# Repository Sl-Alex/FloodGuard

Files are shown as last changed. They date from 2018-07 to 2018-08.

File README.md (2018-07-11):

# General description
Autonomous flood protection system, which can work for months from a single 18650 Li-ion battery.
Includes a battery charger as well as a HW monitoring circuit. Includes power MOSFET for external valve control circuit. Even if SW is stuck or microcontroller is dead you will hear beeping informing you that something is wrong.
Two protected guard inputs make a redundant and reliable system.

# Hardware
Both schematic and PCB were created with KiCAD. KiCAD project is located in the PCB subfolder. Project uses components from my [KiCAD_libs](https://github.com/Sl-Alex/KiCAD_libs) repository.<br />

# Software
Project is created in [EmBitz](https://www.embitz.org/). Project skeleton is created in STM32CubeMX.<br />

# Licensing
The whole project is available under GPL v3 license (see [LICENSE](LICENSE) file), except of files, which clearly mention other license type in the file header.

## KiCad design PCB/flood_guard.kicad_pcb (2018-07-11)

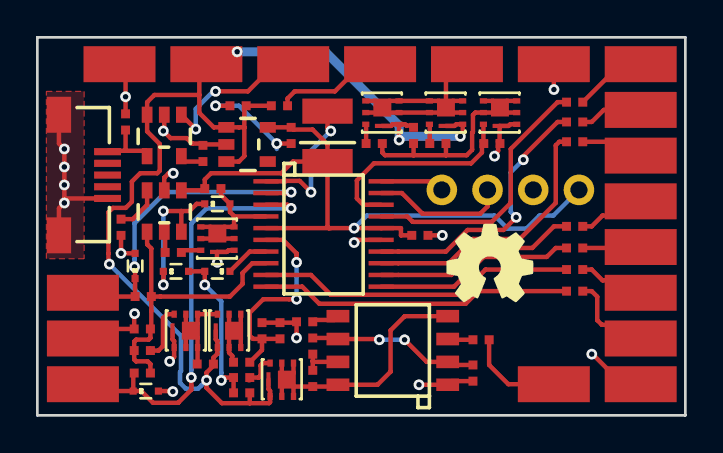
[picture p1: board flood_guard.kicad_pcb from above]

Board: 2 copper layers, 36.0 x 21.0 mm, 77 parts (0 on the bottom side), 49 nets.

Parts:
C1, C2, C3, C4, C5, C7, C8: capacitor; 0402_C
C6: capacitor_el; case_B
D1, D2, D3: diode; SOD523
D4, D5: zener; SOD523
LG?1: LOGO; OSHW
R1, R2, R3, R4, R5, R6, R7, R8, R9, R10, R11, R12, R13, R14, R15, R16, R17, R18, R19, R20, R21, R22, R23, R24, R25, R26, R27, R28: resistor; 0402_R
U1: TPL5010; SOT23-6
U2: NCP551; SOT23-5
U3: TS555CN; SO8
U4: STC4054; SOT23-5
U5: STM32F030F4P6; TSSOP20
VT1, VT2, VT3: MOSFET_N_DGS; PQFN2x2
VT4, VT6, VT7, VT8: MOSFET_P_DGS; PQFN2x2
X1: USB2_MICRO_B_F1
X2: BUZZER+; PLS1_SMD
X4: BAT+; PLS1_SMD
X5: BAT-; PLS1_SMD
X6: CHG_LED-; PLS1_SMD
X7: CHG_LED+; PLS1_SMD
X8: 3V3; PLS1
X9: GND; PLS1
X10: SWCLK; PLS1
X11: SWDIO; PLS1
X12: VOUT; PLS1_SMD
X13, X16, X25: GND; PLS1_SMD
X14: GUARD0; PLS1_SMD
X15: GUARD1; PLS1_SMD
X18: LED0; PLS1_SMD
X19: LED1; PLS1_SMD
X20: LED2; PLS1_SMD
X21: LED3; PLS1_SMD
X22: LED4; PLS1_SMD
X23: LED5; PLS1_SMD
X24: LED6; PLS1_SMD

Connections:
3V3: C5.2, C6.1, C7.2, R8.2, U1.1, U2.5, U5.5, U5.16, X8.1
/BUZZER_PWR: R2.2, U3.4, U3.8, VT4.1
/BUZ_EN: D2.2, U5.7
/GUARD0: D4.2, R17.2, U5.2, X14.1
/GUARD1: D5.2, R18.2, U5.3, X15.1
/LED0: R21.1, U5.10
/LED1: R22.1, U5.9
/LED2: R23.1, U5.11
/LED3: R24.1, U5.12
/LED4: R25.1, U5.13
/LED5: R26.1, U5.14
/LED6: R27.1, U5.17
/LOAD: R13.2, U5.18, VT3.2
/MEAS: R11.1, R12.1, R17.1, R18.1, U1.4, U5.8
/SWCLK: U5.20, X10.1
/SWDIO: U5.19, X11.1
/VADC: C8.1, R19.1, R20.2, U5.6
/VBAT: C4.2, R7.1, R9.2, R14.2, R28.1, U2.1, U2.3, U4.3, VT4.3, VT6.3, VT7.3, VT8.3, X4.1
/VOUT: VT6.1, VT8.1, X12.1
/WAKE: R6.1, U1.5
/~CPU_RST: D1.1, R8.1, U5.4, VT1.1
/~RST: D1.2, D3.2, U1.6
GND: C1.1, C2.1, C3.1, C4.1, C5.1, C6.2, C7.1, C8.2, D4.1, D5.1, R1.1, R4.1, R11.2, R13.1, R19.2, U1.2, U2.2, U3.1, U4.2, U5.1, U5.15, VT1.3, VT2.3, VT3.3, X1.5, X1.6, X1.7, X5.1, X9.1, X13.1, X16.1, X25.1
unnamed: C1.2, R3.1, U3.2, U3.6
unnamed: C2.2, U3.5
unnamed: C3.2, U4.4, X1.1
unnamed: D2.1, D3.1, R9.1, R10.1
unnamed: R1.2, U1.3
unnamed: R2.1, R3.2, U3.7
unnamed: R4.2, U4.5
unnamed: R5.1, U3.3
unnamed: R5.2, X2.1
unnamed: R6.2, VT1.2
unnamed: R7.2, X7.1
unnamed: R10.2, VT4.2
unnamed: R12.2, VT2.2
unnamed: R14.1, VT2.1, VT7.2
unnamed: R15.1, VT6.2
unnamed: R15.2, R16.2, R28.2, VT3.1
unnamed: R16.1, VT8.2
unnamed: R20.1, VT7.1
unnamed: R21.2, X18.1
unnamed: R22.2, X19.1
unnamed: R23.2, X20.1
unnamed: R24.2, X21.1
unnamed: R25.2, X22.1
unnamed: R26.2, X23.1
unnamed: R27.2, X24.1
unnamed: U4.1, X6.1

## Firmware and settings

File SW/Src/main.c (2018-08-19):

/**
  ******************************************************************************
  * @file           : main.c
  * @brief          : Main program body
  ******************************************************************************
  ** This notice applies to any and all portions of this file
  * that are not between comment pairs USER CODE BEGIN and
  * USER CODE END. Other portions of this file, whether
  * inserted by the user or by software development tools
  * are owned by their respective copyright owners.
  *
  * COPYRIGHT(c) 2018 STMicroelectronics
  *
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
  ******************************************************************************
  */
/* Includes ------------------------------------------------------------------*/
#include "main.h"
#include "stm32f0xx_hal.h"
#include <stdbool.h>

/* USER CODE BEGIN Includes */
#include "stm32f0xx_hal_adc_ex.h"

/* USER CODE END Includes */

ADC_HandleTypeDef hadc;

/* USER CODE BEGIN PV */
float vdd  = 0;
float vbat = 0;
uint8_t guard0 = 0;
uint8_t guard1 = 0;

#define CLOSED_CYCLES_MAX 2 // How many cycles keep LOAD enabled.
uint8_t closed_cycles __attribute__ ((section (".noinit")));

/* USER CODE END PV */

void SystemClock_Config(void);
static void MX_GPIO_Init(void);
static void MX_ADC_Init(void);

/* USER CODE BEGIN PFP */

/* USER CODE END PFP */

/* USER CODE BEGIN 0 */
/**
  * @brief  Performs all measurements (Vdd, Vbat and GUARDx inputs)
  *
  * @retval None
  */
void getInputs( void )
{
  // Enable measurements
  HAL_GPIO_WritePin(MEAS_GPIO_Port, MEAS_Pin, GPIO_PIN_SET);

  // Wait for inputs to settle
  HAL_Delay(10);

  // Calibrate internal ADC
  HAL_ADCEx_Calibration_Start(&hadc);

  // Perform measurements
  HAL_ADC_Start(&hadc);
  uint16_t vref_cal = *(uint16_t*)0x1FFFF7BA;
  HAL_ADC_PollForConversion(&hadc,10);
  /// Get ADC0
  uint32_t vbat_raw = HAL_ADC_GetValue(&hadc);
  HAL_ADC_Start(&hadc);
  HAL_ADC_PollForConversion(&hadc,10);
  /// Get VREFINT
  uint32_t vref_raw = HAL_ADC_GetValue(&hadc);

  guard0 = (HAL_GPIO_ReadPin(GUARD0_GPIO_Port, GUARD0_Pin) == GPIO_PIN_RESET);
  guard1 = (HAL_GPIO_ReadPin(GUARD1_GPIO_Port, GUARD1_Pin) == GPIO_PIN_RESET);

  // Set global variables
  vdd  = 3.0f * vref_cal / vref_raw;
  vbat = 2.0f * vdd * vbat_raw / 4096; ///< 2.0 is an external voltage divider

  // Disable ADC
  HAL_ADC_Stop(&hadc);
  // Disable measurement pin
  HAL_GPIO_WritePin(MEAS_GPIO_Port, MEAS_Pin, GPIO_PIN_RESET);
}

/**
  * @brief  Shows information on the LED display
  * @details Shows digits from 0 to 9, letters A to F. 0x10 will be displayed as L. The rest will be displayed as blank
  * @retval None
  */
void setLeds( uint8_t value )
{
  switch(value)
  {
    case 0x0:
      HAL_GPIO_WritePin(LED0_GPIO_Port, LED0_Pin, GPIO_PIN_SET);
      HAL_GPIO_WritePin(LED1_GPIO_Port, LED1_Pin, GPIO_PIN_SET);
      HAL_GPIO_WritePin(LED2_GPIO_Port, LED2_Pin, GPIO_PIN_SET);
      HAL_GPIO_WritePin(LED3_GPIO_Port, LED3_Pin, GPIO_PIN_SET);
      HAL_GPIO_WritePin(LED4_GPIO_Port, LED4_Pin, GPIO_PIN_SET);
      HAL_GPIO_WritePin(LED5_GPIO_Port, LED5_Pin, GPIO_PIN_SET);
      break;
    case 0x1:
      HAL_GPIO_WritePin(LED1_GPIO_Port, LED1_Pin, GPIO_PIN_SET);
      HAL_GPIO_WritePin(LED2_GPIO_Port, LED2_Pin, GPIO_PIN_SET);
      break;
    case 0x2:
      HAL_GPIO_WritePin(LED0_GPIO_Port, LED0_Pin, GPIO_PIN_SET);
      HAL_GPIO_WritePin(LED1_GPIO_Port, LED1_Pin, GPIO_PIN_SET);
      HAL_GPIO_WritePin(LED3_GPIO_Port, LED3_Pin, GPIO_PIN_SET);
      HAL_GPIO_WritePin(LED4_GPIO_Port, LED4_Pin, GPIO_PIN_SET);
      HAL_GPIO_WritePin(LED6_GPIO_Port, LED6_Pin, GPIO_PIN_SET);
      break;
    case 0x3:
      HAL_GPIO_WritePin(LED0_GPIO_Port, LED0_Pin, GPIO_PIN_SET);
      HAL_GPIO_WritePin(LED1_GPIO_Port, LED1_Pin, GPIO_PIN_SET);
      HAL_GPIO_WritePin(LED2_GPIO_Port, LED2_Pin, GPIO_PIN_SET);
      HAL_GPIO_WritePin(LED3_GPIO_Port, LED3_Pin, GPIO_PIN_SET);
      HAL_GPIO_WritePin(LED6_GPIO_Port, LED6_Pin, GPIO_PIN_SET);
      break;
    case 0x4:
      HAL_GPIO_WritePin(LED1_GPIO_Port, LED1_Pin, GPIO_PIN_SET);
      HAL_GPIO_WritePin(LED2_GPIO_Port, LED2_Pin, GPIO_PIN_SET);
      HAL_GPIO_WritePin(LED5_GPIO_Port, LED5_Pin, GPIO_PIN_SET);
      HAL_GPIO_WritePin(LED6_GPIO_Port, LED6_Pin, GPIO_PIN_SET);
      break;
    case 0x5:
      HAL_GPIO_WritePin(LED0_GPIO_Port, LED0_Pin, GPIO_PIN_SET);
      HAL_GPIO_WritePin(LED2_GPIO_Port, LED2_Pin, GPIO_PIN_SET);
      HAL_GPIO_WritePin(LED3_GPIO_Port, LED3_Pin, GPIO_PIN_SET);
      HAL_GPIO_WritePin(LED5_GPIO_Port, LED5_Pin, GPIO_PIN_SET);
      HAL_GPIO_WritePin(LED6_GPIO_Port, LED6_Pin, GPIO_PIN_SET);
      break;
    case 0x6:
      HAL_GPIO_WritePin(LED0_GPIO_Port, LED0_Pin, GPIO_PIN_SET);
      HAL_GPIO_WritePin(LED2_GPIO_Port, LED2_Pin, GPIO_PIN_SET);
      HAL_GPIO_WritePin(LED3_GPIO_Port, LED3_Pin, GPIO_PIN_SET);
      HAL_GPIO_WritePin(LED4_GPIO_Port, LED4_Pin, GPIO_PIN_SET);
      HAL_GPIO_WritePin(LED5_GPIO_Port, LED5_Pin, GPIO_PIN_SET);
      HAL_GPIO_WritePin(LED6_GPIO_Port, LED6_Pin, GPIO_PIN_SET);
      break;
    case 0x7:
      HAL_GPIO_WritePin(LED0_GPIO_Port, LED0_Pin, GPIO_PIN_SET);
      HAL_GPIO_WritePin(LED1_GPIO_Port, LED1_Pin, GPIO_PIN_SET);
      HAL_GPIO_WritePin(LED2_GPIO_Port, LED2_Pin, GPIO_PIN_SET);
      break;
    case 0x8:
      HAL_GPIO_WritePin(LED0_GPIO_Port, LED0_Pin, GPIO_PIN_SET);
      HAL_GPIO_WritePin(LED1_GPIO_Port, LED1_Pin, GPIO_PIN_SET);
      HAL_GPIO_WritePin(LED2_GPIO_Port, LED2_Pin, GPIO_PIN_SET);
      HAL_GPIO_WritePin(LED3_GPIO_Port, LED3_Pin, GPIO_PIN_SET);
      HAL_GPIO_WritePin(LED4_GPIO_Port, LED4_Pin, GPIO_PIN_SET);
      HAL_GPIO_WritePin(LED5_GPIO_Port, LED5_Pin, GPIO_PIN_SET);
      HAL_GPIO_WritePin(LED6_GPIO_Port, LED6_Pin, GPIO_PIN_SET);
      break;
    case 0x9:
      HAL_GPIO_WritePin(LED0_GPIO_Port, LED0_Pin, GPIO_PIN_SET);
      HAL_GPIO_WritePin(LED1_GPIO_Port, LED1_Pin, GPIO_PIN_SET);
      HAL_GPIO_WritePin(LED2_GPIO_Port, LED2_Pin, GPIO_PIN_SET);
      HAL_GPIO_WritePin(LED3_GPIO_Port, LED3_Pin, GPIO_PIN_SET);
      HAL_GPIO_WritePin(LED5_GPIO_Port, LED5_Pin, GPIO_PIN_SET);
      HAL_GPIO_WritePin(LED6_GPIO_Port, LED6_Pin, GPIO_PIN_SET);
      break;
    case 0xA:
      HAL_GPIO_WritePin(LED0_GPIO_Port, LED0_Pin, GPIO_PIN_SET);
      HAL_GPIO_WritePin(LED1_GPIO_Port, LED1_Pin, GPIO_PIN_SET);
      HAL_GPIO_WritePin(LED2_GPIO_Port, LED2_Pin, GPIO_PIN_SET);
      HAL_GPIO_WritePin(LED4_GPIO_Port, LED4_Pin, GPIO_PIN_SET);
      HAL_GPIO_WritePin(LED5_GPIO_Port, LED5_Pin, GPIO_PIN_SET);
      HAL_GPIO_WritePin(LED6_GPIO_Port, LED6_Pin, GPIO_PIN_SET);
      break;
    case 0xB:
      HAL_GPIO_WritePin(LED2_GPIO_Port, LED2_Pin, GPIO_PIN_SET);
      HAL_GPIO_WritePin(LED3_GPIO_Port, LED3_Pin, GPIO_PIN_SET);
      HAL_GPIO_WritePin(LED4_GPIO_Port, LED4_Pin, GPIO_PIN_SET);
      HAL_GPIO_WritePin(LED5_GPIO_Port, LED5_Pin, GPIO_PIN_SET);
      HAL_GPIO_WritePin(LED6_GPIO_Port, LED6_Pin, GPIO_PIN_SET);
      break;
    case 0xC:
      HAL_GPIO_WritePin(LED0_GPIO_Port, LED0_Pin, GPIO_PIN_SET);
      HAL_GPIO_WritePin(LED3_GPIO_Port, LED3_Pin, GPIO_PIN_SET);
      HAL_GPIO_WritePin(LED4_GPIO_Port, LED4_Pin, GPIO_PIN_SET);
      HAL_GPIO_WritePin(LED5_GPIO_Port, LED5_Pin, GPIO_PIN_SET);
      break;
    case 0xD:
      HAL_GPIO_WritePin(LED1_GPIO_Port, LED1_Pin, GPIO_PIN_SET);
      HAL_GPIO_WritePin(LED2_GPIO_Port, LED2_Pin, GPIO_PIN_SET);
      HAL_GPIO_WritePin(LED3_GPIO_Port, LED3_Pin, GPIO_PIN_SET);
      HAL_GPIO_WritePin(LED4_GPIO_Port, LED4_Pin, GPIO_PIN_SET);
      HAL_GPIO_WritePin(LED6_GPIO_Port, LED6_Pin, GPIO_PIN_SET);
      break;
    case 0xE:
      HAL_GPIO_WritePin(LED0_GPIO_Port, LED0_Pin, GPIO_PIN_SET);
      HAL_GPIO_WritePin(LED3_GPIO_Port, LED3_Pin, GPIO_PIN_SET);
      HAL_GPIO_WritePin(LED4_GPIO_Port, LED4_Pin, GPIO_PIN_SET);
      HAL_GPIO_WritePin(LED5_GPIO_Port, LED5_Pin, GPIO_PIN_SET);
      HAL_GPIO_WritePin(LED6_GPIO_Port, LED6_Pin, GPIO_PIN_SET);
      break;
    case 0xF:
      HAL_GPIO_WritePin(LED0_GPIO_Port, LED0_Pin, GPIO_PIN_SET);
      HAL_GPIO_WritePin(LED4_GPIO_Port, LED4_Pin, GPIO_PIN_SET);
      HAL_GPIO_WritePin(LED5_GPIO_Port, LED5_Pin, GPIO_PIN_SET);
      HAL_GPIO_WritePin(LED6_GPIO_Port, LED6_Pin, GPIO_PIN_SET);
      break;
    case 0x10: // "L"
      HAL_GPIO_WritePin(LED3_GPIO_Port, LED3_Pin, GPIO_PIN_SET);
      HAL_GPIO_WritePin(LED4_GPIO_Port, LED4_Pin, GPIO_PIN_SET);
      HAL_GPIO_WritePin(LED5_GPIO_Port, LED5_Pin, GPIO_PIN_SET);
      break;
    default:
      HAL_GPIO_WritePin(LED0_GPIO_Port, LED0_Pin, GPIO_PIN_RESET);
      HAL_GPIO_WritePin(LED1_GPIO_Port, LED1_Pin, GPIO_PIN_RESET);
      HAL_GPIO_WritePin(LED2_GPIO_Port, LED2_Pin, GPIO_PIN_RESET);
      HAL_GPIO_WritePin(LED3_GPIO_Port, LED3_Pin, GPIO_PIN_RESET);
      HAL_GPIO_WritePin(LED4_GPIO_Port, LED4_Pin, GPIO_PIN_RESET);
      HAL_GPIO_WritePin(LED5_GPIO_Port, LED5_Pin, GPIO_PIN_RESET);
      HAL_GPIO_WritePin(LED6_GPIO_Port, LED6_Pin, GPIO_PIN_RESET);
      break;
  }
}
/* USER CODE END 0 */

/**
  * @brief  The application entry point.
  *
  * @retval None
  */
int main(void)
{
  /* MCU Configuration----------------------------------------------------------*/

  /* Reset of all peripherals, Initializes the Flash interface and the Systick. */
  HAL_Init();

  /* Configure the system clock */
  SystemClock_Config();

  /* Initialize all configured peripherals */
  MX_GPIO_Init();
  MX_ADC_Init();
  /* Infinite loop */
  /* USER CODE BEGIN WHILE */

  getInputs();
  // Clear LEDs
  setLeds(0xFF);

  if ((guard0 != 0) || (guard1 != 0) || (vbat < 3.3f))
  {
    // Enable load only for the specified number of cycles
    if (closed_cycles < CLOSED_CYCLES_MAX)
    {
        closed_cycles++;
        // Flood detected or battery is low, enable LOAD
        HAL_GPIO_WritePin(LOAD_GPIO_Port, LOAD_Pin, GPIO_PIN_SET);
    }
    if ((guard0 != 0) && (guard1 == 0))
    {
      setLeds(0x0); // GUARD0 error
    }
    else if ((guard0 == 0) && (guard1 != 0))
    {
      setLeds(0x1); // GUARD1 error
    }
    else if ((guard0 != 0) && (guard1 != 0))
    {
      setLeds(0xb); // Both GUARDs error
    }
    else
    {
      setLeds(0x10); // Battery low, will be displayed as "L"
    }

    // 100ms beep
    HAL_GPIO_WritePin(BUZ_EN_GPIO_Port, BUZ_EN_Pin, GPIO_PIN_RESET);
    HAL_Delay(100);
    HAL_GPIO_WritePin(BUZ_EN_GPIO_Port, BUZ_EN_Pin, GPIO_PIN_SET);
    while(1){};
  }
  else
  {
    // Clear if everything is OK
    closed_cycles = 0;
    if (vbat < 3.4f)
    {
      setLeds(0x1);
      HAL_GPIO_WritePin(BUZ_EN_GPIO_Port, BUZ_EN_Pin, GPIO_PIN_RESET);
    }
    else if (vbat < 3.5f)
    {
      setLeds(0x2);
    }
    else if (vbat < 3.6f)
    {
      setLeds(0x3);
    }
    else if (vbat < 3.7f)
    {
      setLeds(0x4);
    }
    else if (vbat < 3.8f)
    {
      setLeds(0x5);
    }
    else if (vbat < 3.9f)
    {
      setLeds(0x6);
    }
    else if (vbat < 4.0f)
    {
      setLeds(0x7);
    }
    else if (vbat < 4.1f)
    {
      setLeds(0x8);
    }
    else if (vbat < 4.2f)
    {
      setLeds(0x9);
    }
    /// Wait a bit before disabling LEDs
    HAL_Delay(100);
    setLeds(0xFF);
    // Disable beeper
    HAL_GPIO_WritePin(BUZ_EN_GPIO_Port, BUZ_EN_Pin, GPIO_PIN_SET);
  }

#ifdef RELEASE
  HAL_PWR_EnterSTANDBYMode();
#endif
  while (1)
  {
  /* USER CODE END WHILE */

  /* USER CODE BEGIN 3 */
  }
  /* USER CODE END 3 */

}

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


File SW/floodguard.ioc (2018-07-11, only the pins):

Mcu.UserName=STM32F030F4Px
PA0.GPIO_Label=VADC
PA0.Signal=ADC_IN0
PA1.GPIO_Label=BUZ_EN
PA1.Signal=GPIO_Output
PA10.GPIO_Label=LOAD
PA10.Signal=GPIO_Output
PA2.GPIO_Label=MEAS
PA2.Signal=GPIO_Output
PA3.GPIO_Label=LED1
PA3.Signal=GPIO_Output
PA4.GPIO_Label=LED0
PA4.Signal=GPIO_Output
PA5.GPIO_Label=LED2
PA5.Signal=GPIO_Output
PA6.GPIO_Label=LED3
PA6.Signal=GPIO_Output
PA7.GPIO_Label=LED4
PA7.Signal=GPIO_Output
PA9.GPIO_Label=LED6
PA9.Signal=GPIO_Output
PB1.GPIO_Label=LED5
PB1.Signal=GPIO_Output
PF0-OSC_IN.GPIO_Label=GUARD0
PF0-OSC_IN.Signal=GPIO_Input
PF1-OSC_OUT.GPIO_Label=GUARD1
PF1-OSC_OUT.Signal=GPIO_Input

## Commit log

2018-07-11 First version, it works, but can be improved further.
    [flood_guard.kicad_pcb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]
2018-08-19 Schematic update (correct pull-up resistors). Load "ON" time is limited to two cycles.
    [flood_guard.sch]

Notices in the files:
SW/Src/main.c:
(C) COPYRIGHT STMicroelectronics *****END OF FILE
